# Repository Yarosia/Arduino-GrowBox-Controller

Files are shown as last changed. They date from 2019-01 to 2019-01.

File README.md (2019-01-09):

# Arduino GrowBox Controller

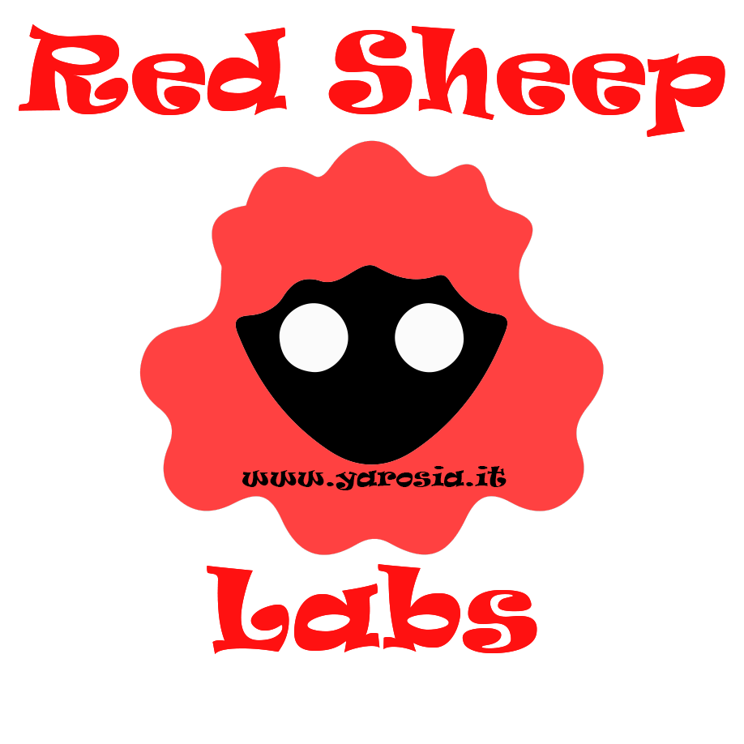
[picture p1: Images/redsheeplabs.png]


Additional documentation can be found at [Red Sheep Labs](https://www.yarosia.it/).

## Recent Changes
- 0.7.7 - 09 Jan 2019
  - First Commit

## Current Status: Testing

My GrowBox is running this firmware from January 2017. Peppers born and grow healty until placed outdoor. 
__I do not assume any responsability for any damage to persons, plants or thing by using this software.__

## License

Arduino GrowBox Controller is published under the [GPL license](/LICENSE) because we believe in open development. The GPL comes with both rights and obligations. Whether you use this GrowBox firmware as the driver for your open or closed-source product, you must keep it open, and you must provide your compatible source code to end users upon request. The most straightforward way to comply with the license is to make a fork of this project on Github, perform your modifications, and direct users to your modified fork.

While we can't prevent the use of this code in products (GrowBox, GermBox, Indoor Gardening etc.) that are closed source or crippled by a patent, we would prefer that you choose another firmware or, better yet, make your own.

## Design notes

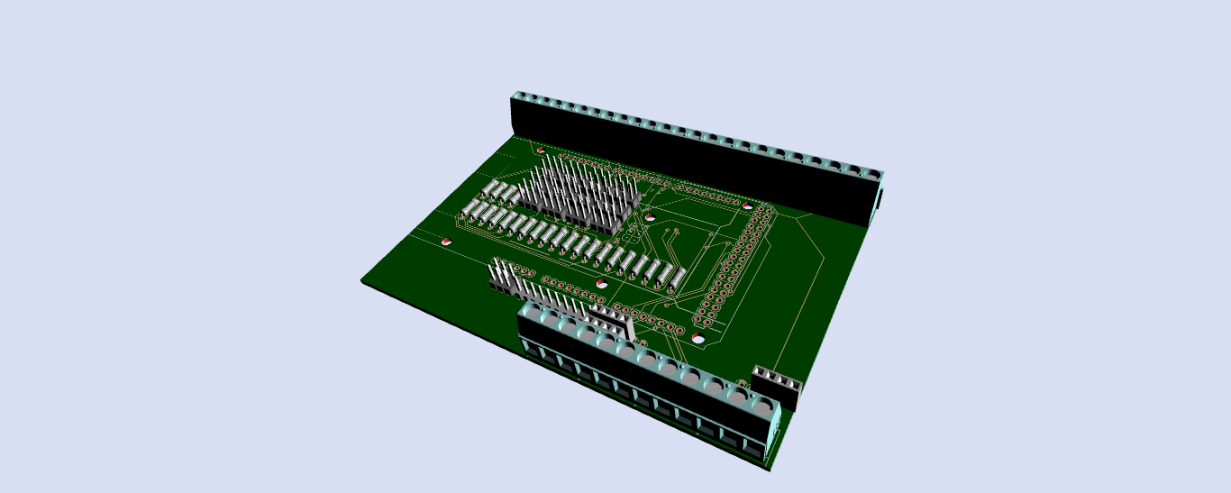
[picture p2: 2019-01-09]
Images/pcb2.png

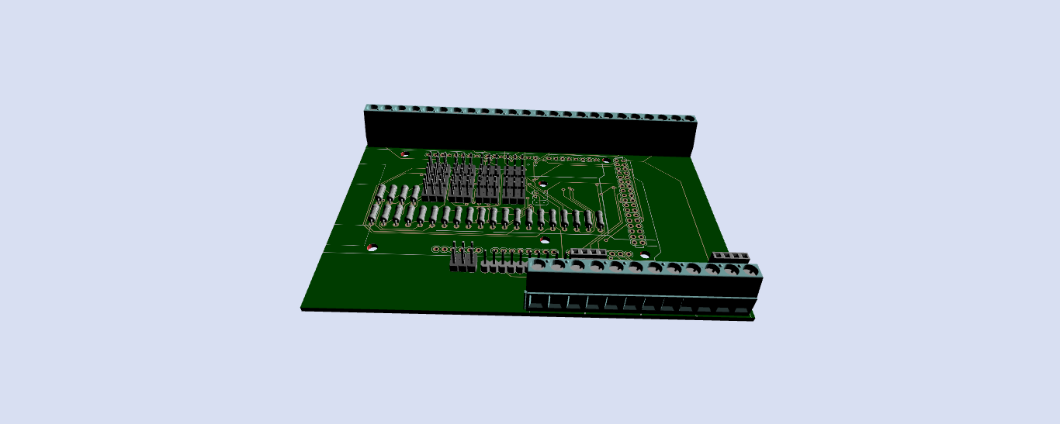
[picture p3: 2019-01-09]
Images/pcb1.png

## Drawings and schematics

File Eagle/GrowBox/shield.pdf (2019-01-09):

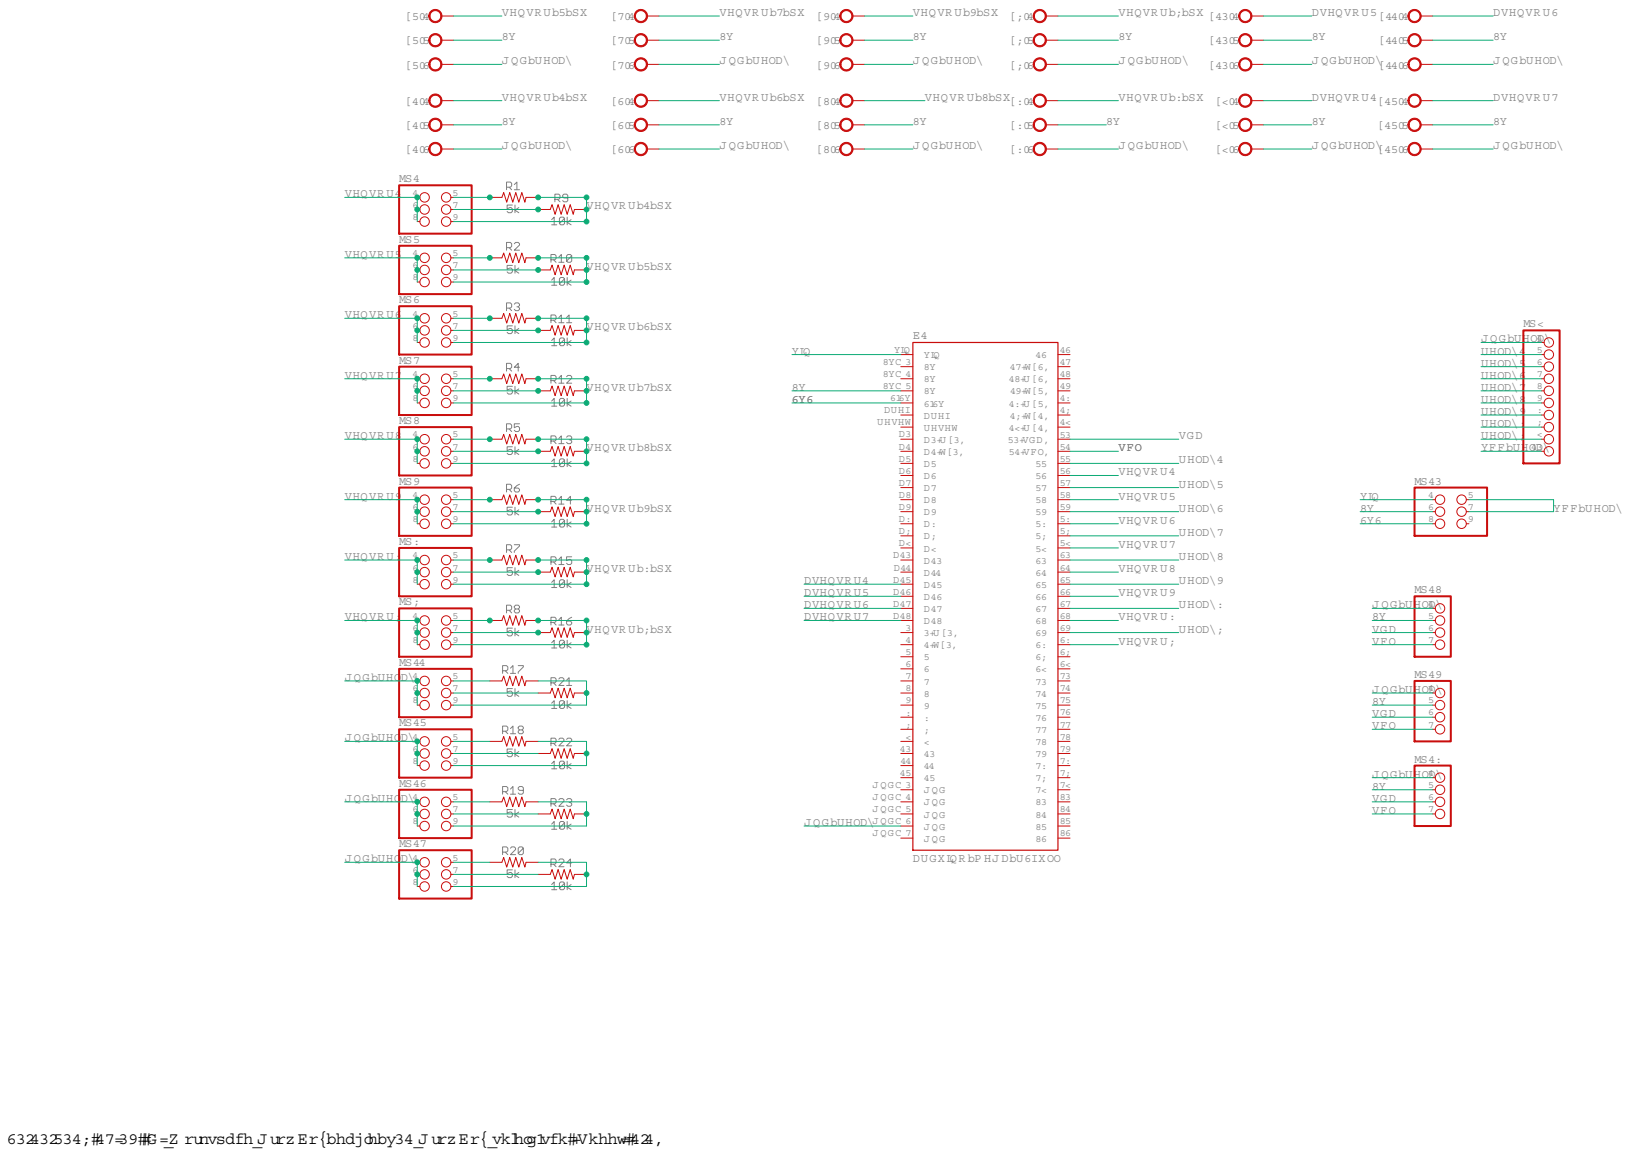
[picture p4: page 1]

W orkspace\Grow Box_eagle_v01\Grow Box\shield.sch (Sheet: 1/1)

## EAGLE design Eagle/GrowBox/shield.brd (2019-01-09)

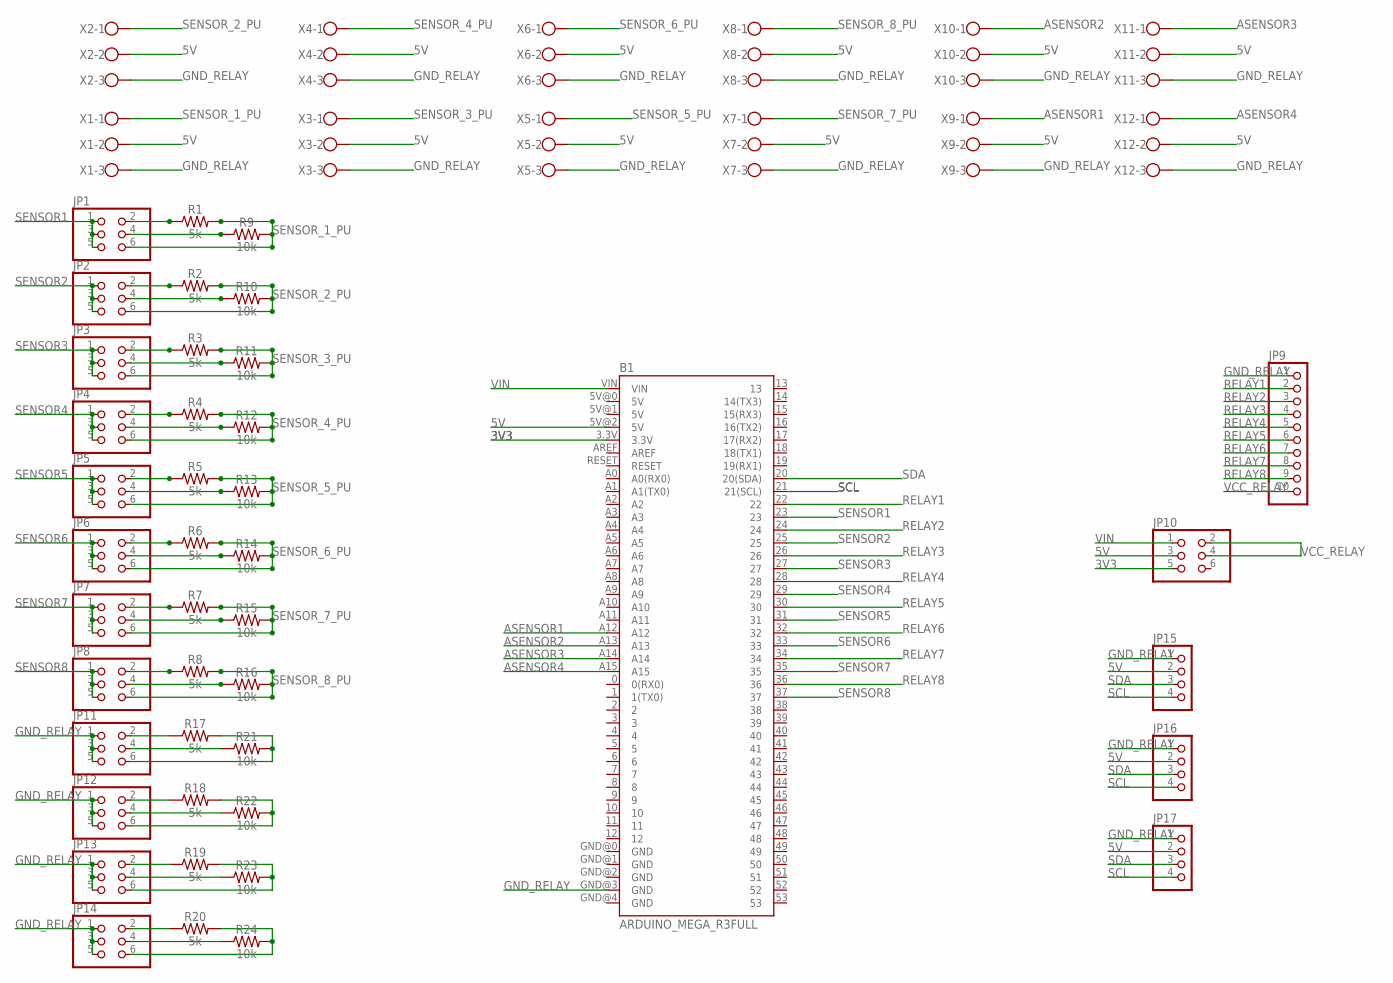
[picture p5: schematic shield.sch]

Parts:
B1: ARDUINO_MEGA_R3FULL; ARDUINO_MEGA
JP1, JP2, JP3, JP4, JP5, JP6, JP7, JP8, JP10, JP11, JP12, JP13, JP14: PINHD-2X3; 2X03
JP9: PINHD-1X10; 1X10
JP15, JP16, JP17: PINHD-1X4; 1X04
R1, R2, R3, R4, R5, R6, R7, R8, R17, R18, R19, R20: 5k; AXIAL-0.3
R9, R10, R11, R12, R13, R14, R15, R16, R21, R22, R23, R24: 10k; AXIAL-0.3
X1, X2, X3, X4, X5, X6, X7, X8, X9, X10, X11, X12: W237-103

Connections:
3V3: B1.3.3V, JP10.5
5V: B1.5V@2 (5V), JP10.3, JP15.2, JP16.2, JP17.2, X1.2, X2.2, X3.2, X4.2, X5.2, X6.2, X7.2, X8.2, X9.2, X10.2, X11.2, X12.2
ASENSOR1: B1.A12, X9.1
ASENSOR2: B1.A13, X10.1
ASENSOR3: B1.A14, X11.1
ASENSOR4: B1.A15, X12.1
GND_RELAY: B1.GND@3 (GND), JP9.1, JP11.1, JP11.3, JP11.5, JP12.1, JP12.3, JP12.5, JP13.1, JP13.3, JP13.5, JP14.1, JP14.3, JP14.5, JP15.1, JP16.1, JP17.1, X1.3, X2.3, X3.3, X4.3, X5.3, X6.3, X7.3, X8.3, X9.3, X10.3, X11.3, X12.3
unnamed: JP2.4, R10.P$1 (1)
unnamed: JP1.4, R9.P$1 (1)
unnamed: JP3.4, R11.P$1 (1)
unnamed: JP4.4, R12.P$1 (1)
unnamed: JP14.2, R20.P$1 (1)
unnamed: JP5.4, R13.P$1 (1)
unnamed: JP14.6, R20.P$2 (2), R24.P$2 (2)
unnamed: JP6.4, R14.P$1 (1)
unnamed: JP14.4, R24.P$1 (1)
unnamed: JP7.4, R15.P$1 (1)
unnamed: JP13.2, R19.P$1 (1)
unnamed: JP8.4, R16.P$1 (1)
unnamed: JP13.6, R19.P$2 (2), R23.P$2 (2)
unnamed: JP13.4, R23.P$1 (1)
unnamed: JP12.2, R18.P$1 (1)
unnamed: JP1.2, R1.P$1 (1)
unnamed: JP2.2, R2.P$1 (1)
unnamed: JP3.2, R3.P$1 (1)
unnamed: JP4.2, R4.P$1 (1)
unnamed: JP5.2, R5.P$1 (1)
unnamed: JP6.2, R6.P$1 (1)
unnamed: JP7.2, R7.P$1 (1)
unnamed: JP8.2, R8.P$1 (1)
unnamed: JP12.6, R18.P$2 (2), R22.P$2 (2)
unnamed: JP12.4, R22.P$1 (1)
unnamed: JP11.2, R17.P$1 (1)
unnamed: JP11.6, R17.P$2 (2), R21.P$2 (2)
unnamed: JP11.4, R21.P$1 (1)
RELAY1: B1.22, JP9.2
RELAY2: B1.24, JP9.3
RELAY3: B1.26, JP9.4
RELAY4: B1.28, JP9.5
RELAY5: B1.30, JP9.6
RELAY6: B1.32, JP9.7
RELAY7: B1.34, JP9.8
RELAY8: B1.36, JP9.9
SCL: B1.21 (21(SCL)), JP15.4, JP16.4, JP17.4
SDA: B1.20 (20(SDA)), JP15.3, JP16.3, JP17.3
SENSOR1: B1.23, JP1.1, JP1.3, JP1.5
SENSOR2: B1.25, JP2.1, JP2.3, JP2.5
SENSOR3: B1.27, JP3.1, JP3.3, JP3.5
SENSOR4: B1.29, JP4.1, JP4.3, JP4.5
SENSOR5: B1.31, JP5.1, JP5.3, JP5.5
SENSOR6: B1.33, JP6.1, JP6.3, JP6.5
SENSOR7: B1.35, JP7.1, JP7.3, JP7.5
SENSOR8: B1.37, JP8.1, JP8.3, JP8.5
SENSOR_1_PU: JP1.6, R1.P$2 (2), R9.P$2 (2), X1.1
SENSOR_2_PU: JP2.6, R2.P$2 (2), R10.P$2 (2), X2.1
SENSOR_3_PU: JP3.6, R3.P$2 (2), R11.P$2 (2), X3.1
SENSOR_4_PU: JP4.6, R4.P$2 (2), R12.P$2 (2), X4.1
SENSOR_5_PU: JP5.6, R5.P$2 (2), R13.P$2 (2), X5.1
SENSOR_6_PU: JP6.6, R6.P$2 (2), R14.P$2 (2), X6.1
SENSOR_7_PU: JP7.6, R7.P$2 (2), R15.P$2 (2), X7.1
SENSOR_8_PU: JP8.6, R8.P$2 (2), R16.P$2 (2), X8.1
VCC_RELAY: JP9.10, JP10.2, JP10.4
VIN: B1.VIN, JP10.1

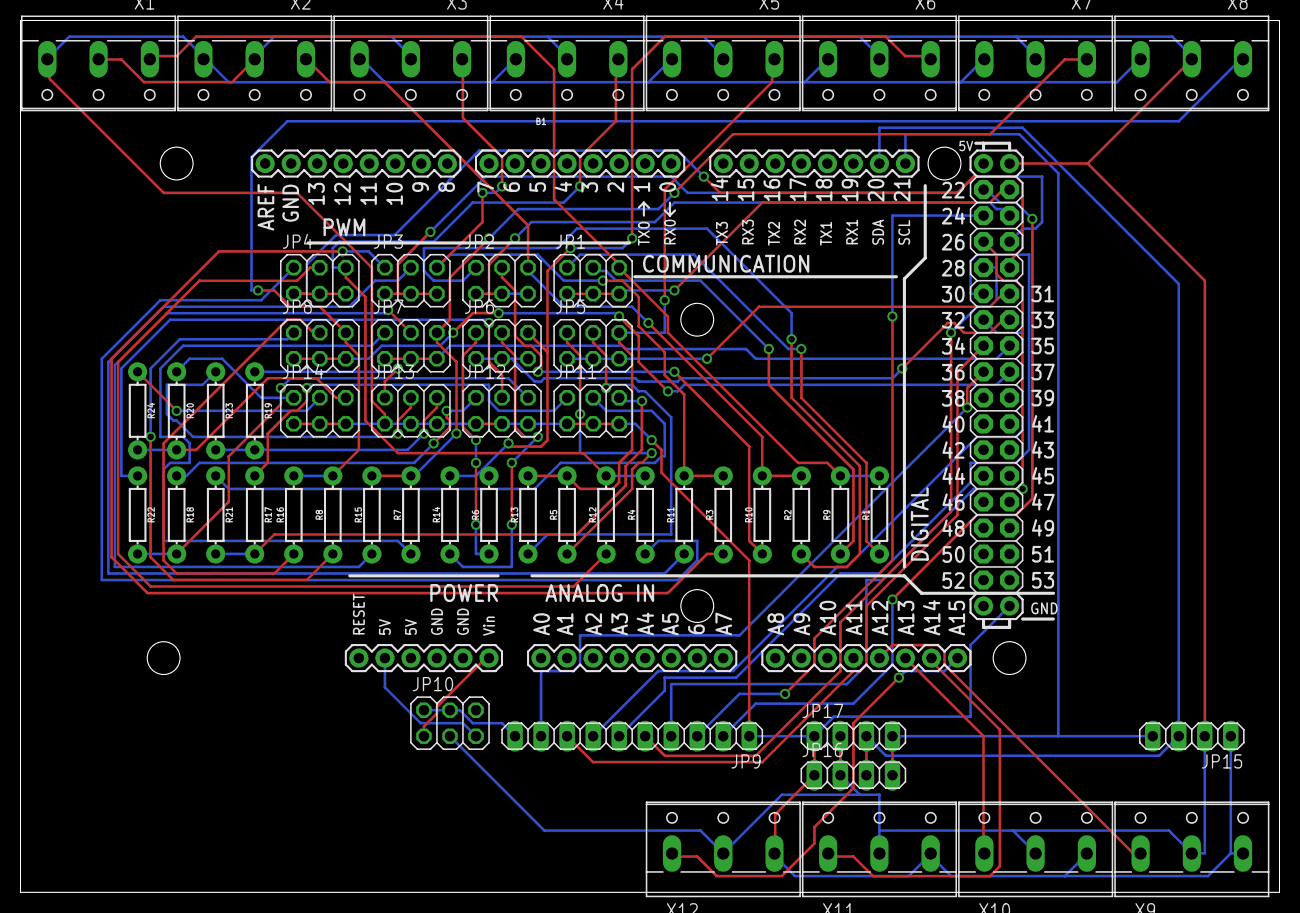
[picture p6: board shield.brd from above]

Board: 2 copper layers, 122.9 x 85.1 mm, 54 parts (0 on the bottom side), 63 nets.

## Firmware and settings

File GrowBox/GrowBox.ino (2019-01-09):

/******************************************************************
  Created with Arduino - 09.12.2015 14:02:04
  Project      : GrowBox v0.7.7 (release.firmware.web)
  Author       : Michele Valentini - Red Sheep Labs
  Description  : GrowBox Controller with EmonCMS interaction
  Website	   : www.yarosia.it
  Email		   : valentini.michele@gmail.com
  Copyright (C): 2015-2018 Michele Valentini (www.yarosia.it - Red Sheep Labs)
  
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
******************************************************************/


//RobTillartDHTlib or AdafruitDHTLib
#define AdafruitDHTLib
//debug or release_version
#define debug

#include <DallasTemperature.h>
#include <DS3232RTC.h>
#include <Streaming.h>
#include <Time.h>
#include <TimeLib.h>
#include <Wire.h>
#include <LiquidCrystal_I2C.h>

#ifdef AdafruitDHTLib
#include <DHT.h>
#endif

#ifdef RobTillartDHTlib
#include <dht.h>
#endif

#include <Ethernet2.h>
#include <SPI.h>
#include <SD.h>
#include <EEPROM.h>
#include <string.h>

#ifdef AdafruitDHTLib
#define TEMPHUM DHT22
#endif

#define RELAYON  0
#define RELAYOFF 1
#define REQ_BUFF_SZ 120

#define LCD_SENSORS 0
#define LCD_NETWORK 1
#define LCD_RELAYS 2
#define LCD_INIT 3

//Increase this if EEPROM changes are made
#define EEPROM_VERSION 5

#define LIGHTS 0
#define HEATER 1
#define FAN 2
#define MIST 3

const int ethCS = 53;
const int sdCS = 4;
const int internalTHpin_PIN = 29;
const int externalTHpin_PIN = 27;
const int internalTEMP_PIN = 25;
const int sampleTEMP_PIN = 23;

const int pinDisable = 10;

/** Relays **/
const int relay_Lights1 = 22;
const int relay_Heater1 = 24;
const int relay_Fan1 = 26;
const int relay_Water1 = 28;
const int relay_Lights2 = 30;
const int relay_Heater2 = 32;
const int relay_Fan2 = 34;
const int relay_Water2 = 36;

/** EEPROM Addresses **/
const int addFirstRun = 0;
const int addLightOnHour = 1;
const int addLightOnMinute = 2;
const int addLightOffHour = 3;
const int addLightOffMinute = 4;
const int addMinIntTemp = 5;
const int addMaxIntTemp = 9;
const int addMinIntHum = 13;
const int addMaxIntHum = 17;
const int addTransmissionRate = 21;
const int addSampleRate = 25;
const int addFanIntervalNight = 29;
const int addFanDurationNight = 30;
const int addIP1 = 31;
const int addIP2 = 32;
const int addIP3 = 33;
const int addIP4 = 34;
const int addDNS1 = 35;
const int addDNS2 = 36;
const int addDNS3 = 37;
const int addDNS4 = 38;
const int addSNM1 = 39;
const int addSNM2 = 40;
const int addSNM3 = 41;
const int addSNM4 = 42;
const int addGW1 = 43;
const int addGW2 = 44;
const int addGW3 = 45;
const int addGW4 = 46;
const int addDHCPFlag = 47;
const int addFanIntervalDay = 48;
const int addFanDurationDay = 49;
const int addFanAlwaysOnDay = 50;
const int addFanAlwaysOnNight = 51;
const int addMinGroundT = 52;
const int addMaxGroundT = 53;

/** Network Addresses **/
int IP1 = 192;
int IP2 = 168;
int IP3 = 1;

#ifdef release_version
int IP4 = 69;
#endif

#ifdef debug
int IP4 = 140;
#endif

int GW1 = 192;
int GW2 = 168;
int GW3 = 1;
int GW4 = 1;
int SNM1 = 255;
int SNM2 = 255;
int SNM3 = 255;
int SNM4 = 0;
int DNS1 = 8;
int DNS2 = 8;
int DNS3 = 8;
int DNS4 = 8;
boolean DHCPFlag = false;

unsigned long int lastFanStart = 0;
unsigned long int transmissionRate = 300000; //Value in Minutes
unsigned long int sampleRate = 10000; //Value in Seconds
unsigned long int lastPost = 0;
unsigned long int lastUpdate = 0;



#ifdef AdafruitDHTLib
DHT dht_internalTH(internalTHpin_PIN, TEMPHUM);
DHT dht_externalTH(externalTHpin_PIN, TEMPHUM);
#endif

#ifdef RobTillartDHTlib
dht DHT;
#endif

OneWire ow_internalT(internalTEMP_PIN);
OneWire ow_sampleT(sampleTEMP_PIN);
DallasTemperature ds_internalT(&ow_internalT);
DallasTemperature ds_sampleT(&ow_sampleT);
DeviceAddress ds_internalT_add;
DeviceAddress ds_sampleT_add;

float internalT = 0;
float internalH = 0;
float externalT = 0;
float externalH = 0;
float internalT2 = 0;
float sampleT = 0;

const char internalTSerial[] = "internal_t";
const char internalHSerial[] = "internal_h";
const char externalTSerial[] = "external_t";
const char externalHSerial[] = "external_h";
const char internalT2Serial[] = "internal_t_top";
const char sampleTSerial[] = "ground_t";


float minIntTemp = 15;
float maxIntTemp = 30;

float minIntHum = 50;
float maxIntHum = 80;

uint8_t minGroundT = 30;
uint8_t maxGroundT = 35;

uint8_t lightOnHour = 8;
uint8_t lightOnMinute = 30;
uint8_t lightOffHour = 20;
uint8_t lightOffMinute = 30;

uint8_t fanDurationDay = 10; //Value in Minutes
uint8_t fanIntervalDay = 6; //Value in Hours

uint8_t fanDurationNight = 10;
uint8_t fanIntervalNight = 6;

uint8_t fanAlwaysOnDay = false;
uint8_t fanAlwaysOnNight = false;

boolean fanOn = false;
unsigned long fanStartTime;

File logDir;
File currentLog;
char logDirName[] = "/logs/";
String currentLogFileName;

File webFile;
char HTTP_req[REQ_BUFF_SZ] = {0};
char req_index = 0;
boolean RELAY_state[4] = {0, 0, 0, 0};

const String index = "index.htm";
const String download = "download.htm";
const String css = "style.css";
const String settings = "settings.htm";

#ifdef debug
LiquidCrystal_I2C lcd(0x27, 20, 4);
#endif

#ifdef release_version
/** LCD display, address 0x3F, 20x4 **/
LiquidCrystal_I2C lcd(0x3F, 20, 4);
#endif

int lcdPage = LCD_INIT;
unsigned long int lastPageChange = 0;
unsigned long int lcdPageChange = 10000;
boolean display_setup = false;

/** Cloud EmonCMS config **/
const char serverEmon[] = "www.emoncms.org";		//Your EmonCMS location es. www.emoncms.org
const String apikey = "abcdefghijklmnopqrstuvwxyz123456";	//Your EmonCMS APIKEY

#ifdef debug
//NODE TEST - sends data to EmonCMS as node 2
int node = 2;
#endif

#ifdef release_version
//NODE GROWBOX - sends data to EmonCMS as node 1
int node = 1;
#endif

/** Network configuration **/
#ifdef debug
//IP TEST
byte mac[6] = {0x90, 0xa2, 0xda, 0x10, 0x76, 0xd9};
#endif

#ifdef release_version
//IP GROWBOX
byte mac[6] = {0x90, 0xa2, 0xda, 0x10, 0x76, 0xc8};
#endif

IPAddress subnet (255, 255, 255, 0);

int port = 80;
EthernetServer server(port);
EthernetClient client;

/** Utility **/
const byte degree[8] = { //  CHARACTER "°C" DEFINITION
  B10111,
  B01000,
  B10000,
  B10000,
  B10000,
  B01000,
  B00111,
};

String addZero(uint16_t data) {
  if (data < 10) {
    return "0" + (String)data;
  } else {
    return (String)data;
  }
}

char* intToDay(uint8_t day) {
  switch (day) {
    case 1:
      return "Sunday";
      break;
    case 2:
      return "Monday";
      break;
    case 3:
      return "Tuesday";
      break;
    case 4:
      return "Wednesday";
      break;
    case 5:
      return "Thursday";
      break;
    case 6:
      return "Friday";
      break;
    case 7:
      return "Saturday";
      break;
    default:
      return "";
      break;
  }
}

/** EEPROM **/
void initializeParameters() {
  // On first run writes default parameters to EEPROM
  int PREVIOUS_EEPROM_VERSION = EEPROM.read(addFirstRun);
  if (PREVIOUS_EEPROM_VERSION < EEPROM_VERSION || PREVIOUS_EEPROM_VERSION == 255) {
  
#ifdef debug
    Serial.println(F("Write EEPROM with default parameters"));
#endif

    EEPROM.put(addFirstRun, EEPROM_VERSION);
    EEPROM.put(addLightOnHour, lightOnHour);
    EEPROM.put(addLightOnMinute, lightOnMinute);
    EEPROM.put(addLightOffHour, lightOffHour);
    EEPROM.put(addLightOffMinute, lightOffMinute);
    EEPROM.put(addMinIntTemp, minIntTemp);
    EEPROM.put(addMaxIntTemp, maxIntTemp);
    EEPROM.put(addMinIntHum, minIntHum);
    EEPROM.put(addMaxIntHum, maxIntHum);
    EEPROM.put(addTransmissionRate, transmissionRate);
    EEPROM.put(addSampleRate, sampleRate);
    EEPROM.put(addFanIntervalNight, fanIntervalNight);
    EEPROM.put(addFanDurationNight, fanDurationNight);
    EEPROM.put(addFanIntervalDay, fanIntervalDay);
    EEPROM.put(addFanDurationDay, fanDurationDay);
    EEPROM.put(addFanAlwaysOnDay, fanAlwaysOnDay);
    EEPROM.put(addFanAlwaysOnNight, fanAlwaysOnNight);
    EEPROM.put(addIP1, IP1);
    EEPROM.put(addIP2, IP2);
    EEPROM.put(addIP3, IP3);
    EEPROM.put(addIP4, IP4);
    EEPROM.put(addGW1, GW1);
    EEPROM.put(addGW2, GW2);
    EEPROM.put(addGW3, GW3);
    EEPROM.put(addGW4, GW4);
    EEPROM.put(addSNM1, SNM1);
    EEPROM.put(addSNM2, SNM2);
    EEPROM.put(addSNM3, SNM3);
    EEPROM.put(addSNM4, SNM4);
    EEPROM.put(addDNS1, DNS1);
    EEPROM.put(addDNS2, DNS2);
    EEPROM.put(addDNS3, DNS3);
    EEPROM.put(addDNS4, DNS4);
    EEPROM.put(addDHCPFlag, DHCPFlag);
    EEPROM.put(addMinGroundT, minGroundT);
    EEPROM.put(addMaxGroundT, maxGroundT);
  }
  
#ifdef debug
  Serial.println(F("Reading EEPROM"));
#endif

  EEPROM.get(addLightOnHour, lightOnHour);
  EEPROM.get(addLightOnMinute, lightOnMinute);
  EEPROM.get(addLightOffHour, lightOffHour);
  EEPROM.get(addLightOffMinute, lightOffMinute);
  EEPROM.get(addMinIntTemp, minIntTemp);
  EEPROM.get(addMaxIntTemp, maxIntTemp);
  EEPROM.get(addMinIntHum, minIntHum);
  EEPROM.get(addMaxIntHum, maxIntHum);
  EEPROM.get(addTransmissionRate, transmissionRate);
  EEPROM.get(addSampleRate, sampleRate);
  EEPROM.get(addFanIntervalNight, fanIntervalNight);
  EEPROM.get(addFanDurationNight, fanDurationNight);
  EEPROM.get(addFanIntervalDay, fanIntervalDay);
  EEPROM.get(addFanDurationDay, fanDurationDay);
  EEPROM.get(addFanAlwaysOnDay, fanAlwaysOnDay);
  EEPROM.get(addFanAlwaysOnNight, fanAlwaysOnNight);
  EEPROM.get(addIP1, IP1);
  EEPROM.get(addIP2, IP2);
  EEPROM.get(addIP3, IP3);
  EEPROM.get(addIP4, IP4);
  EEPROM.get(addGW1, GW1);
  EEPROM.get(addGW2, GW2);
  EEPROM.get(addGW3, GW3);
  EEPROM.get(addGW4, GW4);
  EEPROM.get(addSNM1, SNM1);
  EEPROM.get(addSNM2, SNM2);
  EEPROM.get(addSNM3, SNM3);
  EEPROM.get(addSNM4, SNM4);
  EEPROM.get(addDNS1, DNS1);
  EEPROM.get(addDNS2, DNS2);
  EEPROM.get(addDNS3, DNS3);
  EEPROM.get(addDNS4, DNS4);
  EEPROM.get(addDHCPFlag, DHCPFlag);
  EEPROM.get(addMinGroundT, minGroundT);
  EEPROM.get(addMaxGroundT, maxGroundT);
  
#ifdef debug
  Serial.println("First Run: " + (String) EEPROM.read(addFirstRun));
  Serial.println("Light On Hour: " + (String) lightOnHour);
  Serial.println("Light On Minute: " + (String) lightOnMinute);
  Serial.println("Light Off Hour: " + (String) lightOffHour);
  Serial.println("Light Off Minute: " + (String) lightOffMinute);
  Serial.println("Min Temp: " + (String) minIntTemp);
  Serial.println("Max Temp: " + (String) maxIntTemp);
  Serial.println("Min Hum: " + (String) minIntHum);
  Serial.println("Max Hum: " + (String) maxIntHum);
  Serial.println("Sample Rate:" + (String)sampleRate);
  Serial.println("Transmission Rate: " + (String)transmissionRate);
  Serial.println("Fan Interval Day: " + (String)fanIntervalDay);
  Serial.println("Fan Duration Day: " + (String)fanDurationDay);
  Serial.println("Fan Interval Night: " + (String)fanIntervalNight);
  Serial.println("Fan Duration Night: " + (String)fanDurationNight);
  Serial.println("Fan Always On Day: " + (String)fanAlwaysOnDay);
  Serial.println("Fan Always On Night: " + (String)fanAlwaysOnNight);
#endif

}

void setIPAddress(int ip1, int ip2, int ip3, int ip4) {
  IP1 = ip1;
  IP2 = ip2;
  IP3 = ip3;
  IP4 = ip4;
  EEPROM.put(addIP1, IP1);
  EEPROM.put(addIP2, IP2);
  EEPROM.put(addIP3, IP3);
  EEPROM.put(addIP4, IP4);
}

void setSNMAddress(int snm1, int snm2, int snm3, int snm4) {
  SNM1 = snm1;
  SNM2 = snm2;
  SNM3 = snm3;
  SNM4 = snm4;
  EEPROM.put(addSNM1, SNM1);
  EEPROM.put(addSNM2, SNM2);
  EEPROM.put(addSNM3, SNM3);
  EEPROM.put(addSNM4, SNM4);
}

void setGWAddress(int gw1, int gw2, int gw3, int gw4) {
  GW1 = gw1;
  GW2 = gw2;
  GW3 = gw3;
  GW4 = gw4;
  EEPROM.put(addGW1, GW1);
  EEPROM.put(addGW2, GW2);
  EEPROM.put(addGW3, GW3);
  EEPROM.put(addGW4, GW4);
}

void setDNSAddress(int dns1, int dns2, int dns3, int dns4) {
  DNS1 = dns1;
  DNS2 = dns2;
  DNS3 = dns3;
  DNS4 = dns4;
  EEPROM.put(addDNS1, DNS1);
  EEPROM.put(addDNS2, DNS2);
  EEPROM.put(addDNS3, DNS3);
  EEPROM.put(addDNS4, DNS4);
}

void setDHCP(boolean flag) {
  DHCPFlag = flag;
  EEPROM.put(addDHCPFlag, DHCPFlag);
}

void setSampleRate(unsigned long sampleRateI) {
  sampleRate = sampleRateI;
  EEPROM.put(addSampleRate, sampleRate);
}

void setTransmissionRate(unsigned long transmissionRateI) {
  transmissionRate = transmissionRateI;
  EEPROM.put(addTransmissionRate, transmissionRate);
}

void setFanDurationNight(uint8_t fanDurationI) {
  fanDurationNight = fanDurationI;
  EEPROM.put(addFanDurationNight, fanDurationNight);
}

void setFanIntervalNight(uint8_t fanIntervalI) {
  fanIntervalNight = fanIntervalI;
  EEPROM.put(addFanIntervalNight, fanIntervalNight);
}

void setFanDurationDay(uint8_t fanDurationI) {
  fanDurationDay = fanDurationI;
  EEPROM.put(addFanDurationDay, fanDurationDay);
}

void setFanIntervalDay(uint8_t fanIntervalI) {
  fanIntervalDay = fanIntervalI;
  EEPROM.put(addFanIntervalDay, fanIntervalDay);
}

void setFansAlwaysONNight(boolean fanAlwaysOnNightI) {
  fanAlwaysOnNight = fanAlwaysOnNightI;
  EEPROM.put(addFanAlwaysOnNight, fanAlwaysOnNight);
}

void setFansAlwaysONDay(boolean fanAlwaysOnDayI) {
  fanAlwaysOnDay = fanAlwaysOnDayI;
  EEPROM.put(addFanAlwaysOnDay, fanAlwaysOnDay);
}

void setLightOnHour(uint8_t onHour) {
  lightOnHour = onHour;
  EEPROM.put(addLightOnHour, lightOnHour);

}

void setLightOnMinute(uint8_t onMinute) {
  lightOnMinute = onMinute;
  EEPROM.put(addLightOnMinute, lightOnMinute);

}

void setLightOffHour(uint8_t offHour) {
  lightOffHour = offHour;
  EEPROM.put(addLightOffHour, lightOffHour);

}

void setLightOffMinute(uint8_t offMinute) {
  lightOffMinute = offMinute;
  EEPROM.put(addLightOffMinute, lightOffMinute);
}

void setMinHum(float minHum) {
  minIntHum = minHum;
  EEPROM.put(addMinIntHum, minIntHum);
}

void setMaxHum(float maxHum) {
  maxIntHum = maxHum;
  EEPROM.put(addMaxIntHum, maxIntHum);
}

void setMinTemp(float minTemp) {
  minIntTemp = minTemp;
  EEPROM.put(addMinIntTemp, minIntTemp);
}

void setMaxTemp(float maxTemp) {
  maxIntTemp = maxTemp;
  EEPROM.put(addMaxIntTemp, maxIntTemp);
}

void setMinGroundT(uint8_t minGT) {
  minGroundT = minGT;
  EEPROM.put(addMinGroundT, minGroundT);
}

void setMaxGroundT(uint8_t maxGT) {
  maxGroundT = maxGT;
  EEPROM.put(addMaxGroundT, maxGT);
}

/** LCD **/
void lcdDispatch() {
  unsigned long int ora = millis();
  if (ora > lcdPageChange + lastPageChange) {
    lastPageChange = ora;
    switch (lcdPage) {
      case LCD_INIT:
        printHome();
        break;
      case LCD_SENSORS:
        printStatus();
        break;
      case LCD_RELAYS:
        printRelays();
        break;
      case LCD_NETWORK:
        printNetwork();
        break;
      default:
        break;
    }
  }
}

void printHome() {
  char lcdRow0[21] = "     Welcome  to    ";
  char lcdRow1[21] = "   Arduino Growbox  ";
  char lcdRow2[21] = "     Created By     ";
  char lcdRow3[21] = " Michele  Valentini ";
  lcd.clear();
  lcd.setCursor(0, 0);
  lcd.print(lcdRow0);
  lcd.setCursor(0, 1);
  lcd.print(lcdRow1);
  lcd.setCursor(0, 2);
  lcd.print(lcdRow2);
  lcd.setCursor(0, 3);
  lcd.print(lcdRow3);
  lcd.display();
  lcdPage = LCD_SENSORS;
}

void printStatus() {
  lcd.clear();
  lcd.setCursor(0, 0);
  char  lcdRow0[20] = "";
  tmElements_t tm;
  RTC.read(tm);
  sprintf(lcdRow0, "%02d/%02d/%4d %02d:%02d:%02d", tm.Day, tm.Month, (tm.Year + 1970), tm.Hour, tm.Minute, tm.Second);
  lcd.print(lcdRow0);
  lcd.setCursor(0, 1);
  char intT[6];
  char extT[6];
  char intH[6];
  char extH[6];
  char sampT[6];
  char intT2[6];
  dtostrf(internalT, 6, 2, intT);
  lcd.print("T:");
  lcd.setCursor(2, 1);
  lcd.print(intT);
  dtostrf(internalH, 6, 2, intH);
  lcd.setCursor(9, 1);
  lcd.print("H:");
  lcd.setCursor(11, 1);
  lcd.print(intH);
  lcd.setCursor(0, 2);
  lcd.print("T:");
  lcd.setCursor(2, 2);
  dtostrf(externalT, 6, 2, extT);
  lcd.print(extT);
  lcd.setCursor(9, 2);
  lcd.print("H:");
  lcd.setCursor(11, 2);
  dtostrf(externalH, 6, 2, extH);
  lcd.print(extH);
  lcd.setCursor(0, 3);
  lcd.print("T:");
  lcd.setCursor(2, 3);
  dtostrf(internalT2, 6, 2, intT2);
  lcd.print(intT2);
  lcd.setCursor(9, 3);
  lcd.print("T:");
  lcd.setCursor(11, 3);
  dtostrf(sampleT, 6, 2, sampT);
  lcd.print(sampT);
  lcd.display();
  lcdPage = LCD_RELAYS;
}
void printRelays() {
  lcd.clear();
  lcd.setCursor(0, 0);
  lcd.print("Relays:");
  lcd.setCursor(0, 1);
  lcd.print("Lights: ");
  lcd.setCursor(7, 1);
  if (RELAY_state[LIGHTS] == 1) {
    lcd.print("ON");
  } else {
    lcd.print("OFF");
  }
  lcd.setCursor(11, 1);
  lcd.print("Mist: ");
  lcd.setCursor(16, 1);
  if (RELAY_state[MIST] == 1) {
    lcd.print("ON");
  } else {
    lcd.print("OFF");
  }
  lcd.setCursor(0, 2);
  lcd.print("Heater: ");
  lcd.setCursor(7, 2);
  if (RELAY_state[HEATER] == 1) {
    lcd.print("ON");
  } else {
    lcd.print("OFF");
  }
  lcd.setCursor(11, 2);
  lcd.print("Fan: ");
  lcd.setCursor(16, 2);
  if (RELAY_state[FAN] == 1) {
    lcd.print("ON");
  } else {
    lcd.print("OFF");
  }
  lcd.display();
  lcdPage = LCD_NETWORK;
}

void printNetwork() {
  lcd.clear();
  lcd.setCursor(0, 0);
  lcd.print("Network: ");
  lcd.setCursor(0, 1);
  if (DHCPFlag) {
    lcd.print("DHCP Enabled");
  } else {
    lcd.print("DHCP Disabled");
  }
  char lcdRowIP[21];
  sprintf(lcdRowIP, "IP: %d.%d.%d.%d", Ethernet.localIP()[0], Ethernet.localIP()[1], Ethernet.localIP()[2], Ethernet.localIP()[3]);
  lcd.setCursor(0, 2);
  lcd.print(lcdRowIP);
  lcd.display();
  lcdPage = LCD_SENSORS;

}

/** Init **/
void initializePins() {
  pinMode(ethCS, OUTPUT);
  digitalWrite(ethCS, HIGH);
  pinMode(sdCS, OUTPUT);
  digitalWrite(sdCS, HIGH);
  pinMode(pinDisable, OUTPUT);
  digitalWrite(pinDisable, HIGH);
  //set pin 53 as output - needed on Arduino Mega to make SPI work properly
  pinMode(53, OUTPUT);
  digitalWrite(53, HIGH);
  pinMode(50, OUTPUT);
  // digitalWrite(50, HIGH);
  pinMode(51, OUTPUT);
  // digitalWrite(51, HIGH);
  pinMode(52, OUTPUT);
  SPI.begin();
}

void initializeEthShield() {

}

void initializeSDCard() {

#ifdef debug
  Serial.println(F("Initializing SD Card..."));
#endif

  if (!SD.begin(sdCS)) {
  
#ifdef debug
    Serial.println(F("ERROR - SD Card initializations failed!"));
#endif

    return;
  }
  
#ifdef debug
  Serial.println(F("SUCCESS - SD Card initialized!"));
#endif

  if (!SD.exists(index)) {
  
#ifdef debug
    Serial.print(F("ERROR - Can't find "));
    Serial.print(index);
    Serial.println(F(" file!"));
#endif

    return;
  }
  
#ifdef debug
  Serial.print(F("SUCCESS - Found "));
  Serial.print(index);
  Serial.println(F(" file!"));
#endif

  if (!SD.exists(download)) {
  
#ifdef debug
    Serial.print(F("ERROR - Can't find "));
    Serial.print(download);
    Serial.println(F(" file!"));
#endif

    return;
  }
  
#ifdef debug
  Serial.print(F("SUCCESS - Found "));
  Serial.print(download);
  Serial.println(F(" file!"));
#endif

}

void initializeRelays() {
  pinMode(relay_Lights1, OUTPUT);
  digitalWrite(relay_Lights1, RELAYOFF);
  pinMode(relay_Heater1, OUTPUT);
  digitalWrite(relay_Heater1, RELAYOFF);
  pinMode(relay_Fan1, OUTPUT);
  digitalWrite(relay_Fan1, RELAYOFF);
  pinMode(relay_Water1, OUTPUT);
  digitalWrite(relay_Water1, RELAYOFF);
  pinMode(relay_Lights2, OUTPUT);
  digitalWrite(relay_Lights2, RELAYOFF);
  pinMode(relay_Heater2, OUTPUT);
  digitalWrite(relay_Heater2, RELAYOFF);
  pinMode(relay_Fan2, OUTPUT);
  digitalWrite(relay_Fan2, RELAYOFF);
  pinMode(relay_Water2, OUTPUT);
  digitalWrite(relay_Water2, RELAYOFF);
}

void initializeSensors() {
  ds_internalT.begin();
  ds_sampleT.begin();

  ds_internalT.getAddress(ds_internalT_add, 0);
  ds_sampleT.getAddress(ds_sampleT_add, 0);
  ds_internalT.setResolution(ds_internalT_add, 12);
  ds_sampleT.setResolution(ds_sampleT_add, 12);
}

void initializeLCD() {
  lcd.init();
  lcd.backlight();
}

void initializeServer() {
  if (DHCPFlag) {
    Ethernet.begin(mac);
  } else {
    Ethernet.begin(mac, {IP1, IP2, IP3, IP4}, {GW1, GW2, GW3, GW4}, {SNM1, SNM2, SNM3, SNM4});
  }
  server.begin();
  delay(1000);
}

void setup() {
#ifdef debug
  Serial.begin(57600);
#endif
  initializePins();
  initializeParameters();
  initializeEthShield();
  initializeSDCard();
  initializeRelays();
  initializeSensors();
  initializeLCD();
  initializeServer();
  readAllSensors();
  initializeParameters();
  postJSON();
}

void writeToSD() {
  if (SD.exists(logDirName + getFileName())) {
    currentLog = SD.open(logDirName + currentLogFileName, FILE_WRITE);
    if (currentLog) {
    
#ifdef debug
      Serial.println(F("Writing file"));
#endif

      currentLog.println(getSensorString());
      currentLog.close();
    }
  } else {
  
#ifdef debug
    Serial.println(F("File not found, creating..."));
#endif

    SD.mkdir(logDirName);
    currentLog = SD.open(logDirName + currentLogFileName, FILE_WRITE);
    currentLog.println(F("TimeStamp;InternalTemp;InternalHum;ExternalTemp;ExternalHum;InternalTemp2;SampleTemp;Lights;Heater;Fans;Humidifier;"));
    currentLog.close();
  }
}

String getSensorString() {
  String ret;
  ret += getTimeStampForHTML();
  ret += ";";
  ret += (String)internalT + ";";
  ret += (String)internalH + ";";
  ret += (String)externalT + ";";
  ret += (String)externalH  + ";";
  ret += (String)internalT2 + ";";
  ret += (String)sampleT + ";";
  for (int i = 0; i < 4; i++) {
    ret += (String)getState(RELAY_state[i]) + ";";
  }
  return ret;
}
String getState(boolean relay) {
  if (relay) {
    return "ON";
  } else {
    return "OFF";
  }
  return "";
}

/** Sensors Reading **/
void readAllSensors() {
  ds_internalT.requestTemperatures();
  internalT2 = ds_internalT.getTempC(ds_internalT_add);
  ds_sampleT.requestTemperatures();
  sampleT = ds_sampleT.getTempC(ds_sampleT_add);
  
#ifdef AdafruitDHTLib
  internalT = dht_internalTH.readTemperature();
  internalH = dht_internalTH.readHumidity();
  externalT = dht_externalTH.readTemperature();
  externalH = dht_externalTH.readHumidity();
#endif
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
void loop() {
  updateSensors();
  lcdDispatch();
  checkParameters();
  sendToEmonCMS();
  listenForEthernetAJAX();
  //Ethernet.maintain();
}

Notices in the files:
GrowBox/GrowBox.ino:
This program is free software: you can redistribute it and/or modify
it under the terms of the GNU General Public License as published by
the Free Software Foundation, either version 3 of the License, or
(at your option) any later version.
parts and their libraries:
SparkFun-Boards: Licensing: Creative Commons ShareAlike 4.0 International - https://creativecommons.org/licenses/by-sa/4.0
